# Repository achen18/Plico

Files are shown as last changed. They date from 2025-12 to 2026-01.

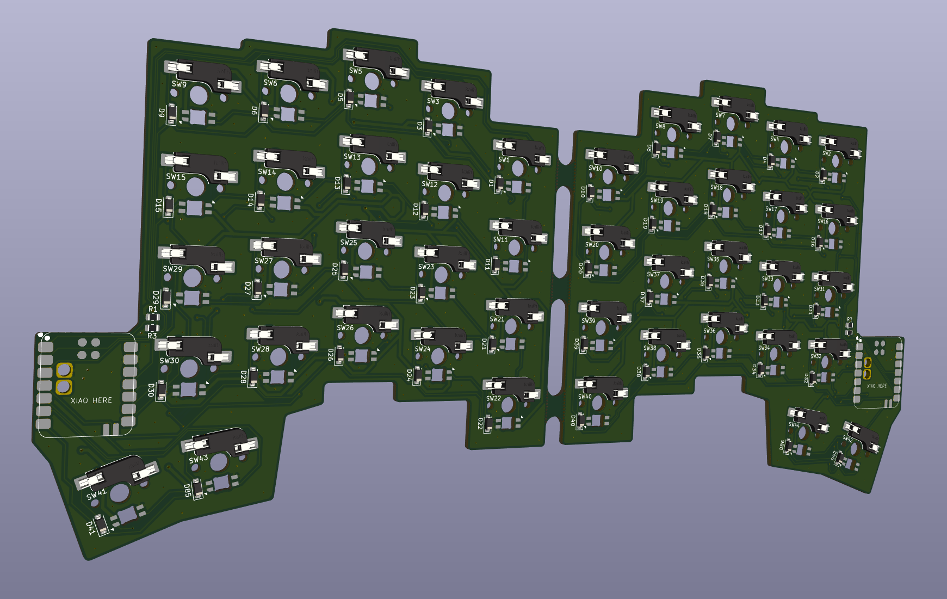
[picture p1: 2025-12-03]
pictures/pcb3DView.png

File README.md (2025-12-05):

# Plico
Fully custom split mechanical keyboard. Runs on ZMK software, controlling key functions and responsive lighting. Future iterations intend to use ultra low-profile switches and a case redesign to allow the two sides to fold together for portability. Firmware updates plan to incorporate layers and macros once the author thinks of what to use so many keys for. 



## PCB
Designed in Kicad

Schematic
schematic

PCB
pcbTraces
pcb3DView

## Case  
3d printed case desinged using Fusion 360. Multiple parts designed for printing with minimal supports. Designed such that no mounting holes needed in pcb. 



## Firmware  
Macropad runs on ZMK software.  
- Split keyboard Bluetooth connection
- 44 keys, full keyboard functionality
- Reactive key leds with fade out effects

To-Do
- Multiple layers for different day-to-day needs. Custom key to easily cycle between layers. Indicate current layer with rgb change. 

## Bill of Materials  
- 2 x XIAO-nRF52840-SMD
- 44 x 1N5819 SMD Diodes
- 44 x MX-Style switches
- 44 x Blank DSA keycaps
- 44 x SK6812-E Reverse Mount LEDs
- 2 x Resistors (1 806k, 1 2M)
- 10 x M3x10 Screws
- 10 x M3x5mx4mm heatset inserts
- 1 x Case (6 3D printed parts - 3 left/right)

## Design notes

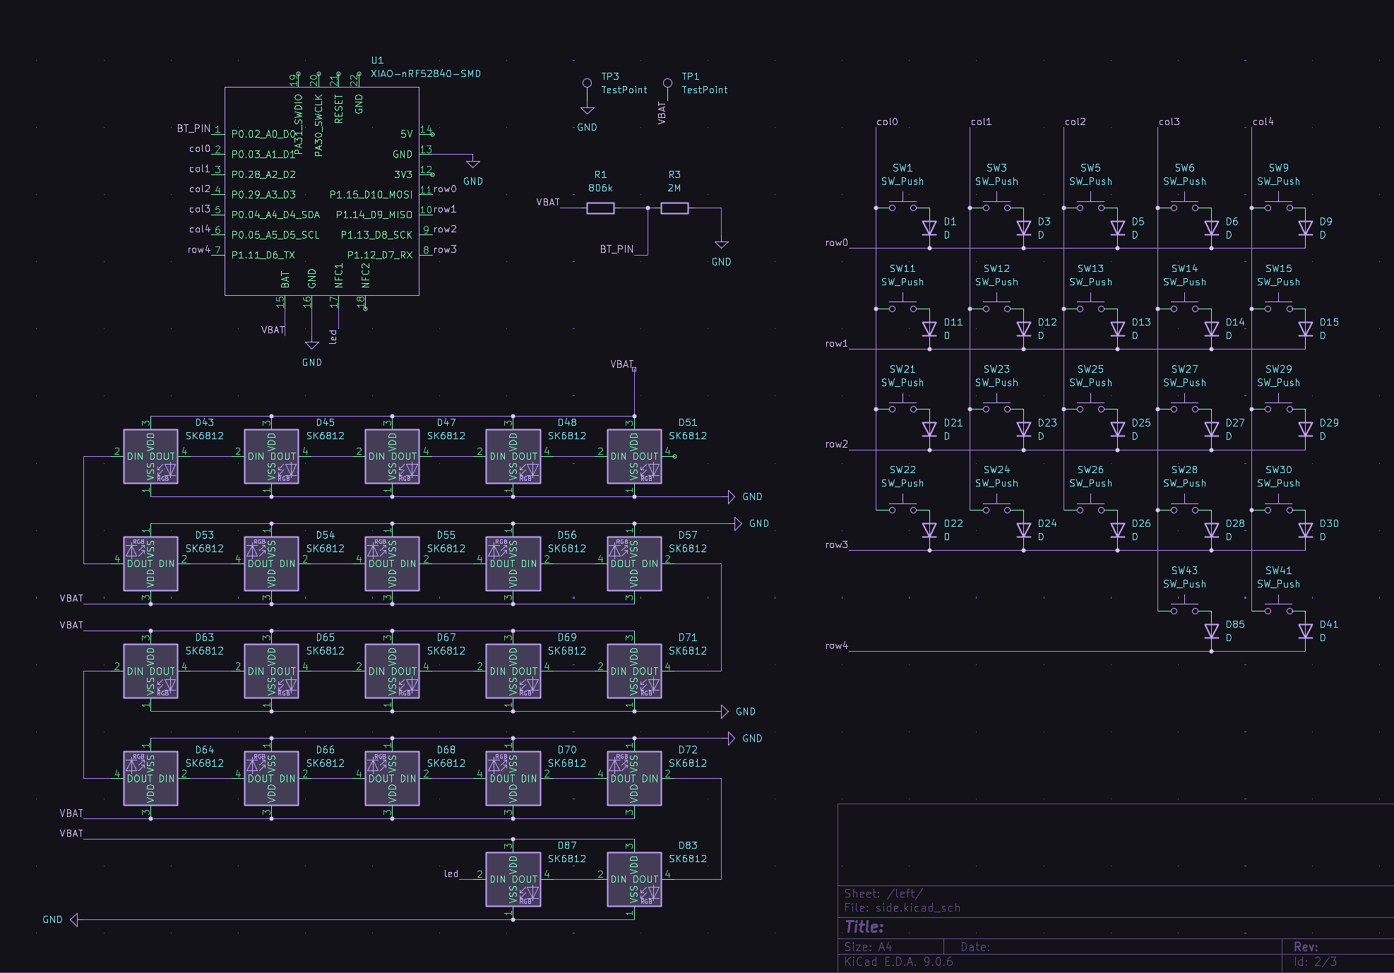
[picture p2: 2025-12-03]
pictures/schematic.png

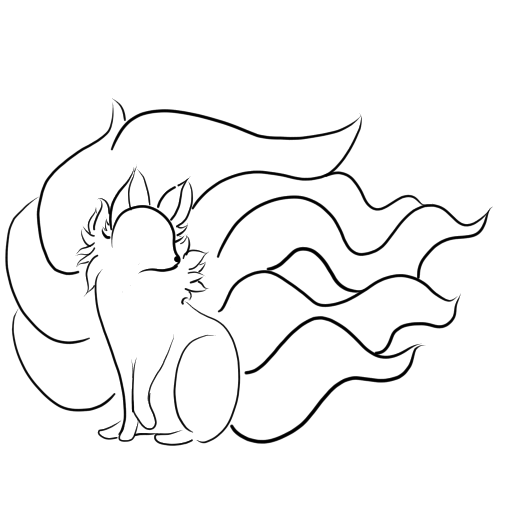
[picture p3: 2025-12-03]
pcb/assets/FoxProfilePurple.kra~.png

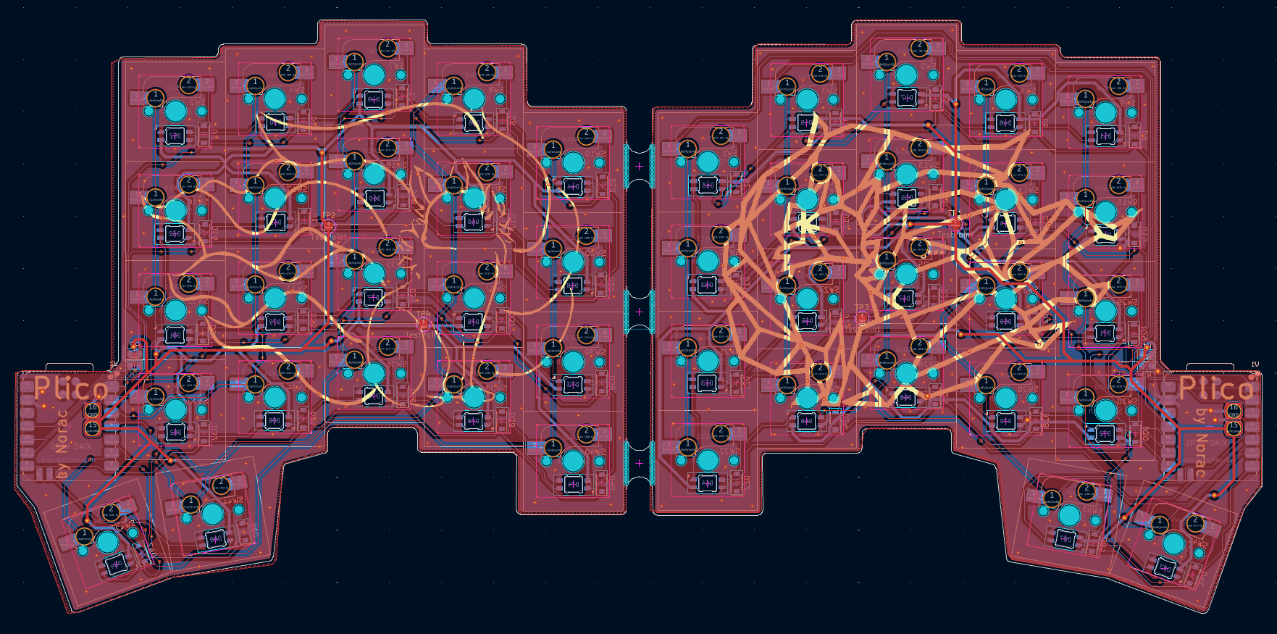
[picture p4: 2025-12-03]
pictures/pcbTraces.png

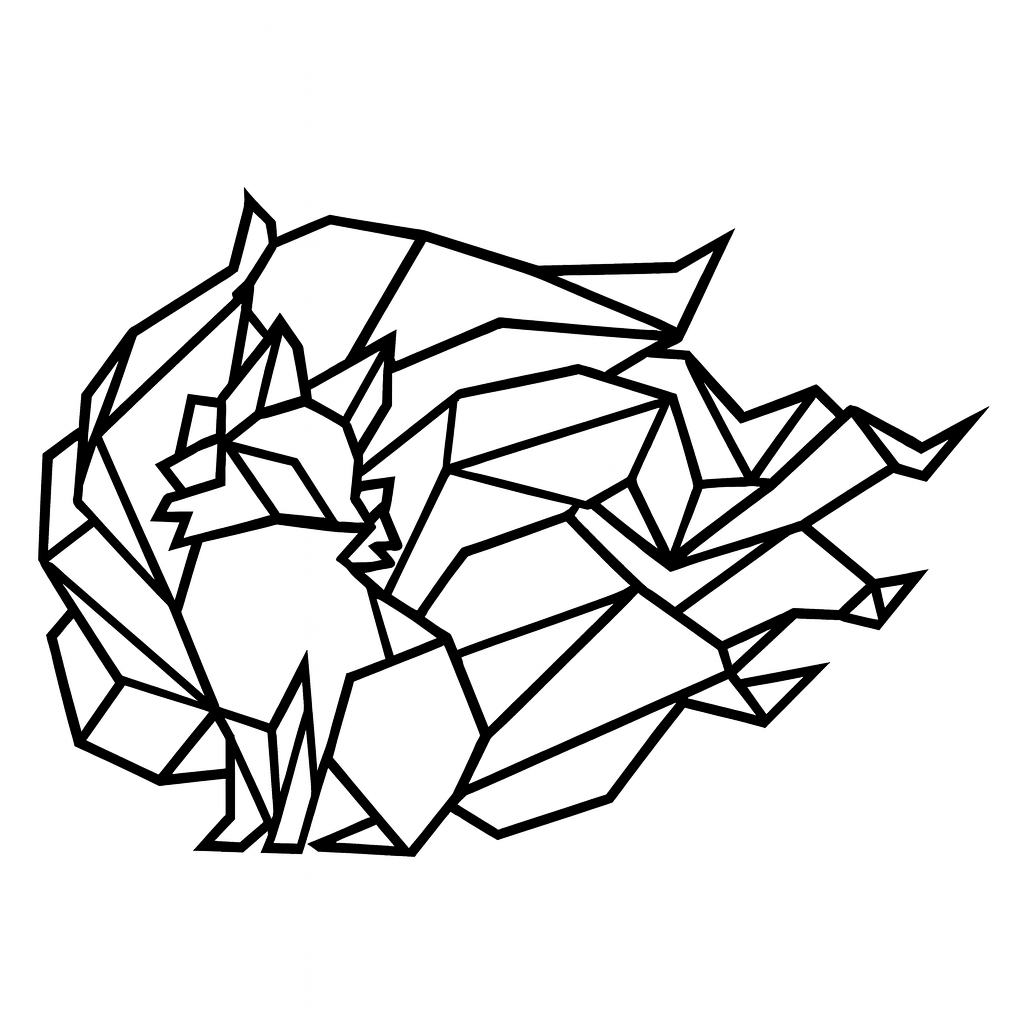
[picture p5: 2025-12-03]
pcb/assets/FoxProfileGeometric.png

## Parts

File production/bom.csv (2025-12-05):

Designator | Footprint | Quantity | Value | LCSC Part #
D1, D10, D11, D12, D13, D14, D15, D16, D17, D18, D19, D2, D20, D21, D22, D23, D24, D25, D26, D27, D28, D29, D3, D30, D31, D32, D33, D34, D35, D36, D37, D38, D39, D4, D40, D41, D42, D5, D6, D7, D8, D85, D86, D9 | D_SOD-123 | 44 | D
D43, D44, D45, D46, D47, D48, D49, D50, D51, D52, D53, D54, D55, D56, D57, D58, D59, D60, D61, D62, D63, D64, D65, D66, D67, D68, D69, D70, D71, D72, D73, D74, D75, D76, D77, D78, D79, D80, D81, D82, D83, D84, D87, D88 | Untitled | 44 | SK6812
R1, R2 | 0805 | 2 | 806k
R3, R4 | 0805 | 2 | 2M
SW1, SW10, SW11, SW12, SW13, SW14, SW15, SW16, SW17, SW18, SW19, SW2, SW20, SW21, SW22, SW23, SW24, SW25, SW26, SW27, SW28, SW29, SW3, SW30, SW31, SW32, SW33, SW34, SW35, SW36, SW37, SW38, SW39, SW4, SW40, SW41, SW42, SW43, SW44, SW5, SW6, SW7, SW8, SW9 | SW_MX_HS_CPG151101S11_1u | 44 | SW_Push
TP1, TP2, TP3, TP4 | TestPoint_Pad_D2.0mm | 4 | TestPoint
U1, U2 | modified-XIAO-nRF52840-SMD | 2 | XIAO-nRF52840-SMD

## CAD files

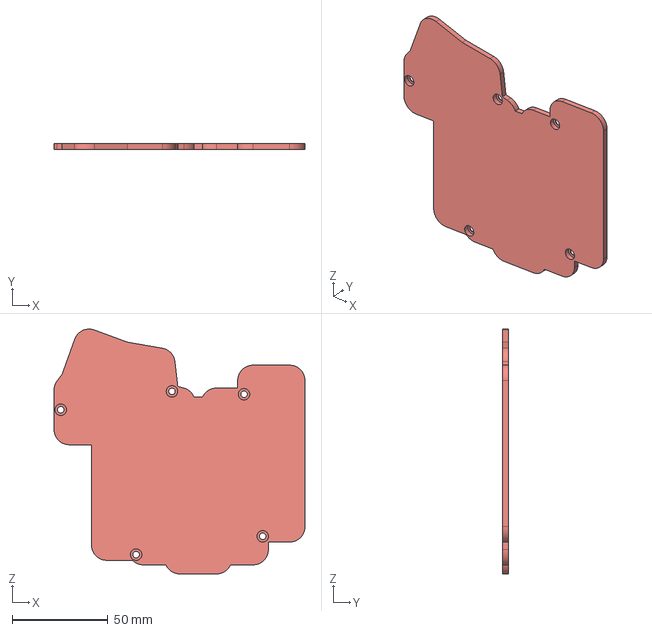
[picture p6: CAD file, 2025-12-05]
cad/bottomRight.step
130.8 x 3.00 x 127.6 mm

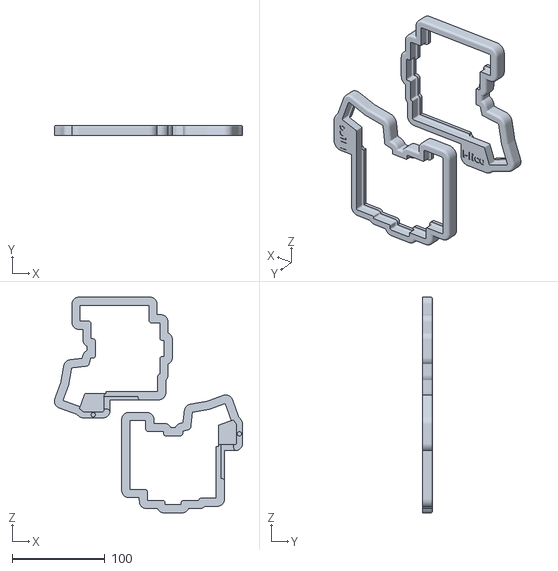
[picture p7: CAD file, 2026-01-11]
production/cad/tops.stl
203.4 x 11.0 x 233.5

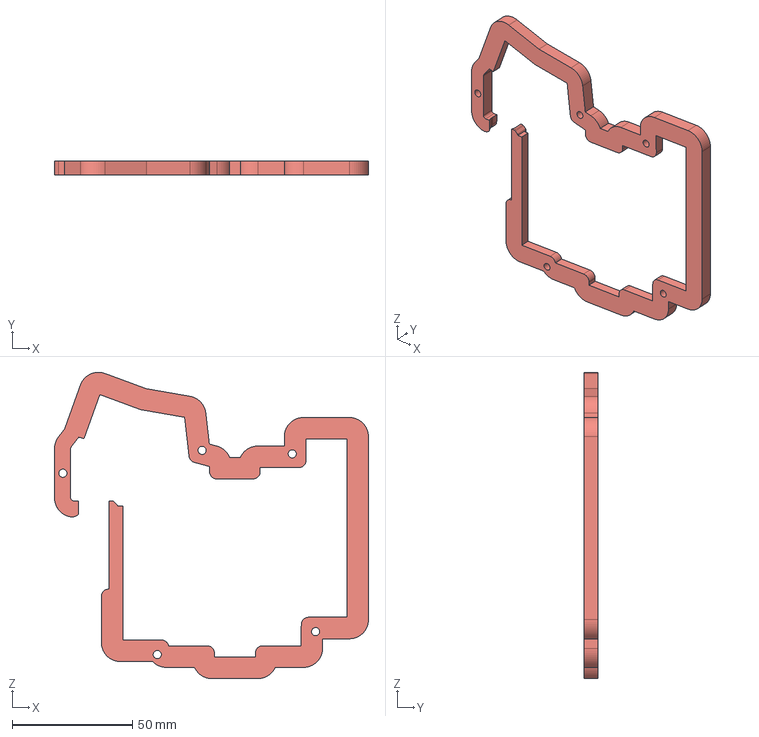
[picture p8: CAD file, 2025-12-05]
cad/middleRight.step
130.8 x 6.01 x 127.6 mm

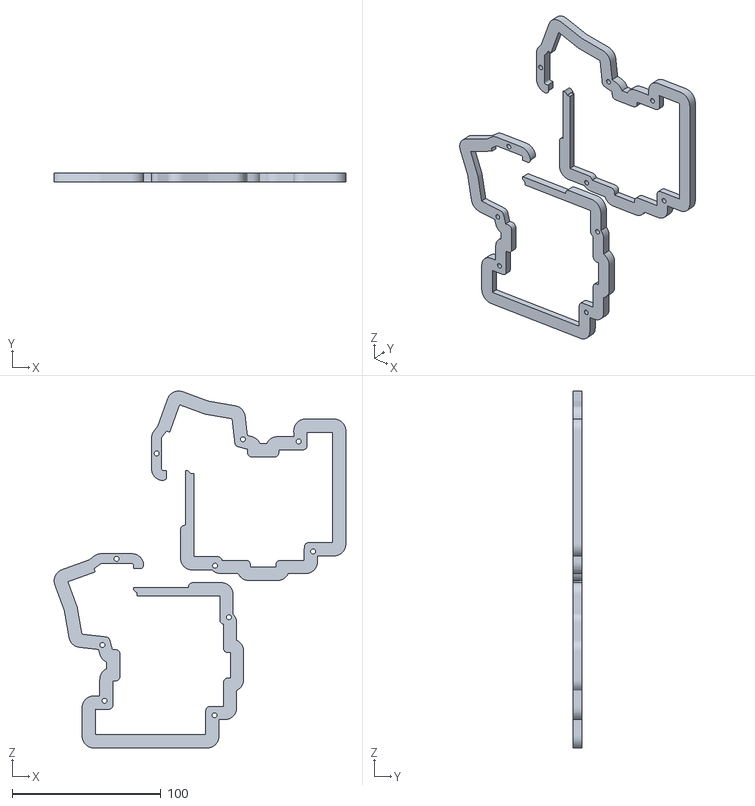
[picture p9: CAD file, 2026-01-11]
production/cad/middles.stl
196.4 x 6.01 x 240.3

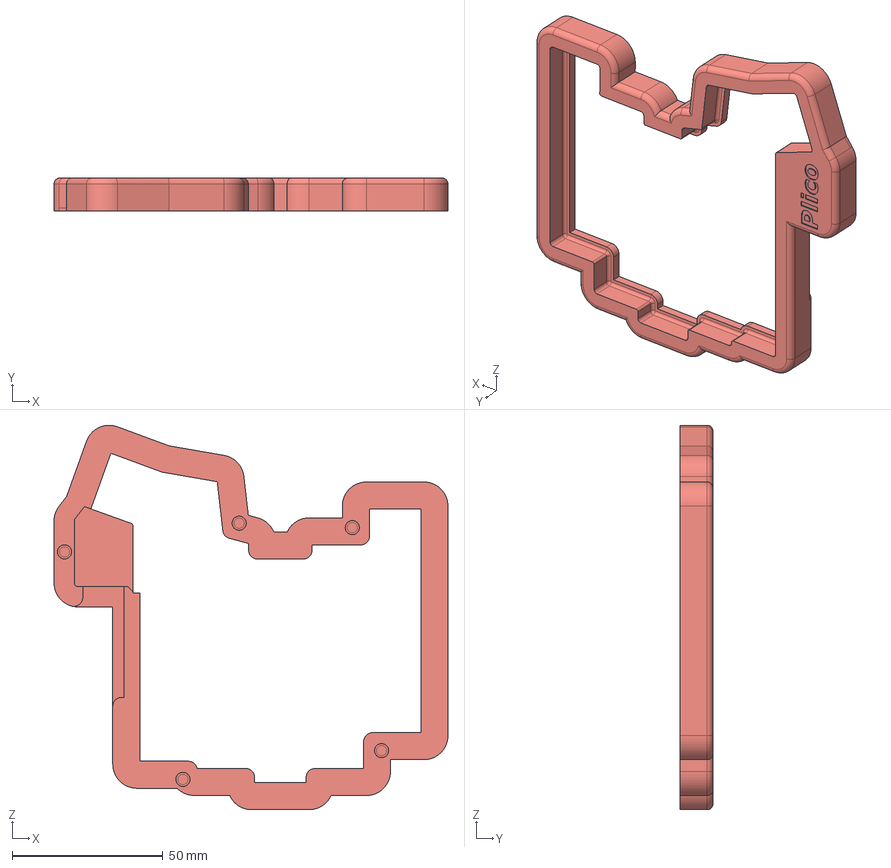
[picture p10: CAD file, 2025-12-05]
cad/topRight.step
130.8 x 11.0 x 127.6 mm

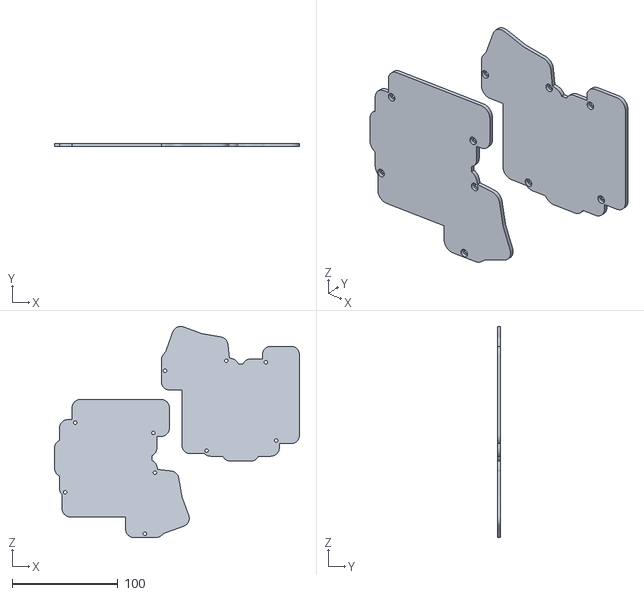
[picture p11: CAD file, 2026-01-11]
production/cad/bottoms.stl
231.9 x 3.00 x 199.9

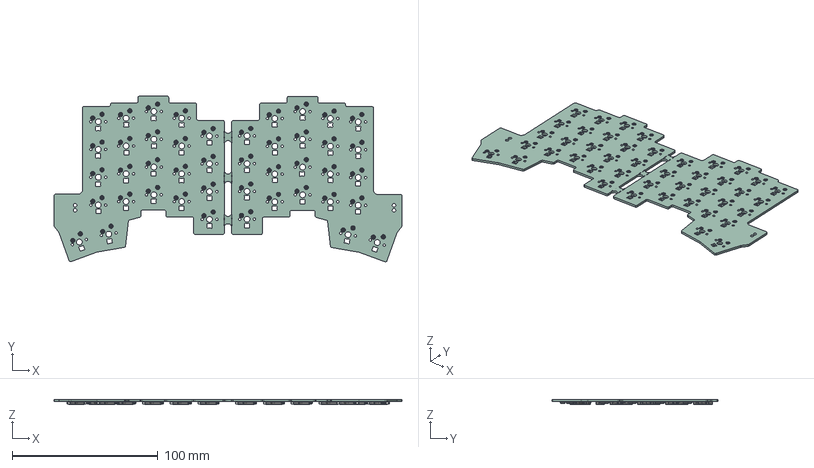
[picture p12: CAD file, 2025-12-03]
cad/Plico.step
238.6 x 113.7 x 3.42 mm
D_SOD-123 x 44
Contact x 88
R_0805_2012Metric x 4
Plico_PCB

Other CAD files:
cad/bottomLeft.step
production/cad/middleLeft.step
cad/topLeft.step
production/cad/bottomLeft.step
cad/middleLeft.step
production/cad/topLeft.step
production/cad/bottomLeft.stl
production/cad/bottomRight.stl
production/cad/middleLeft.stl
production/cad/middleRight.stl
production/cad/topLeft.stl
production/cad/topRight.stl

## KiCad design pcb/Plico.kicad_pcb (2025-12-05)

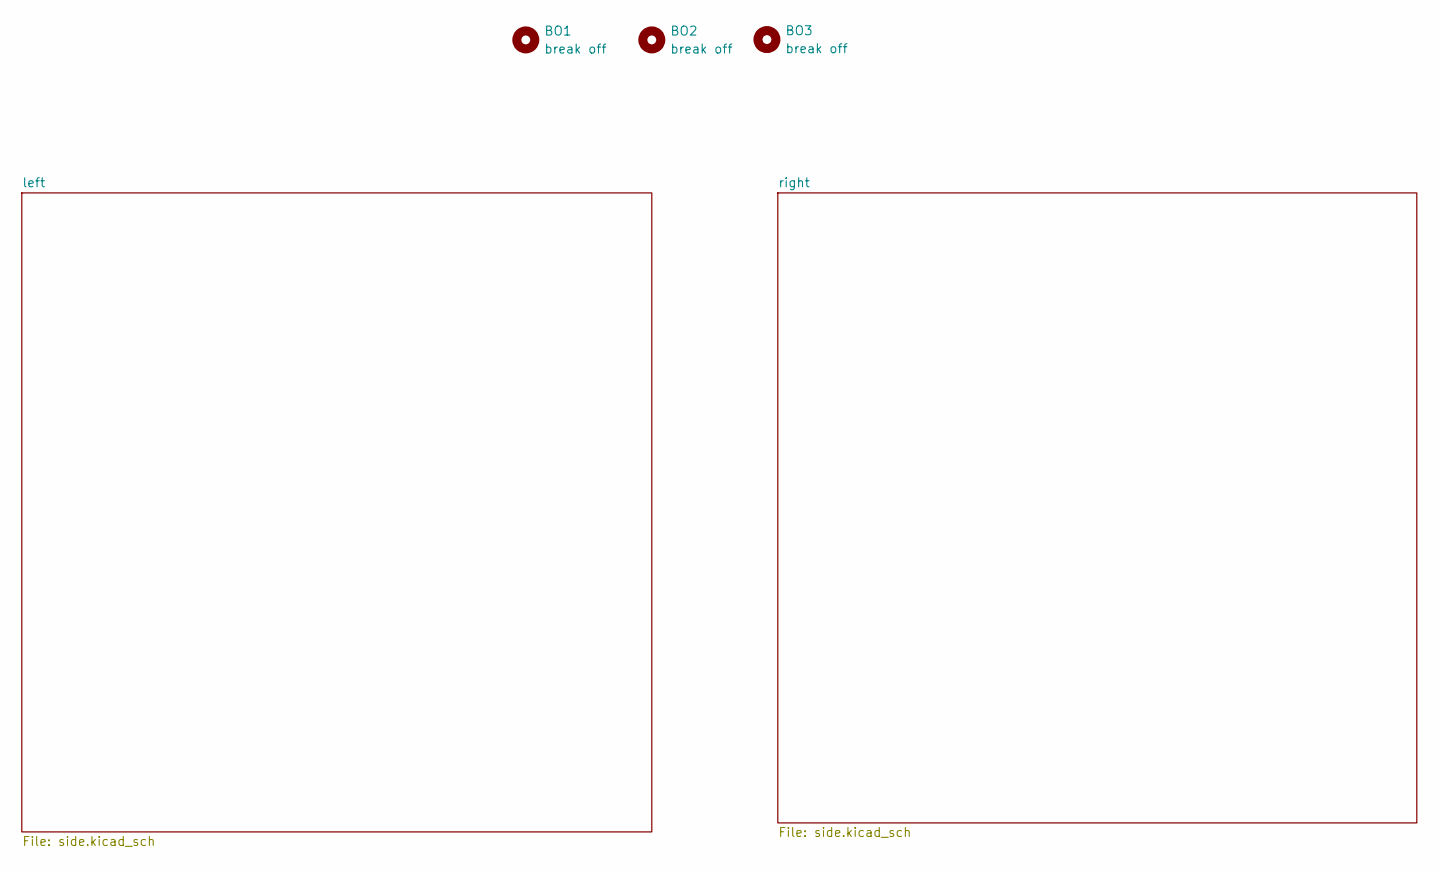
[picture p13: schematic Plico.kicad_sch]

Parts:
BO1, BO2, BO3: break off; mouse-bite-5mm-slot-edgeCuts

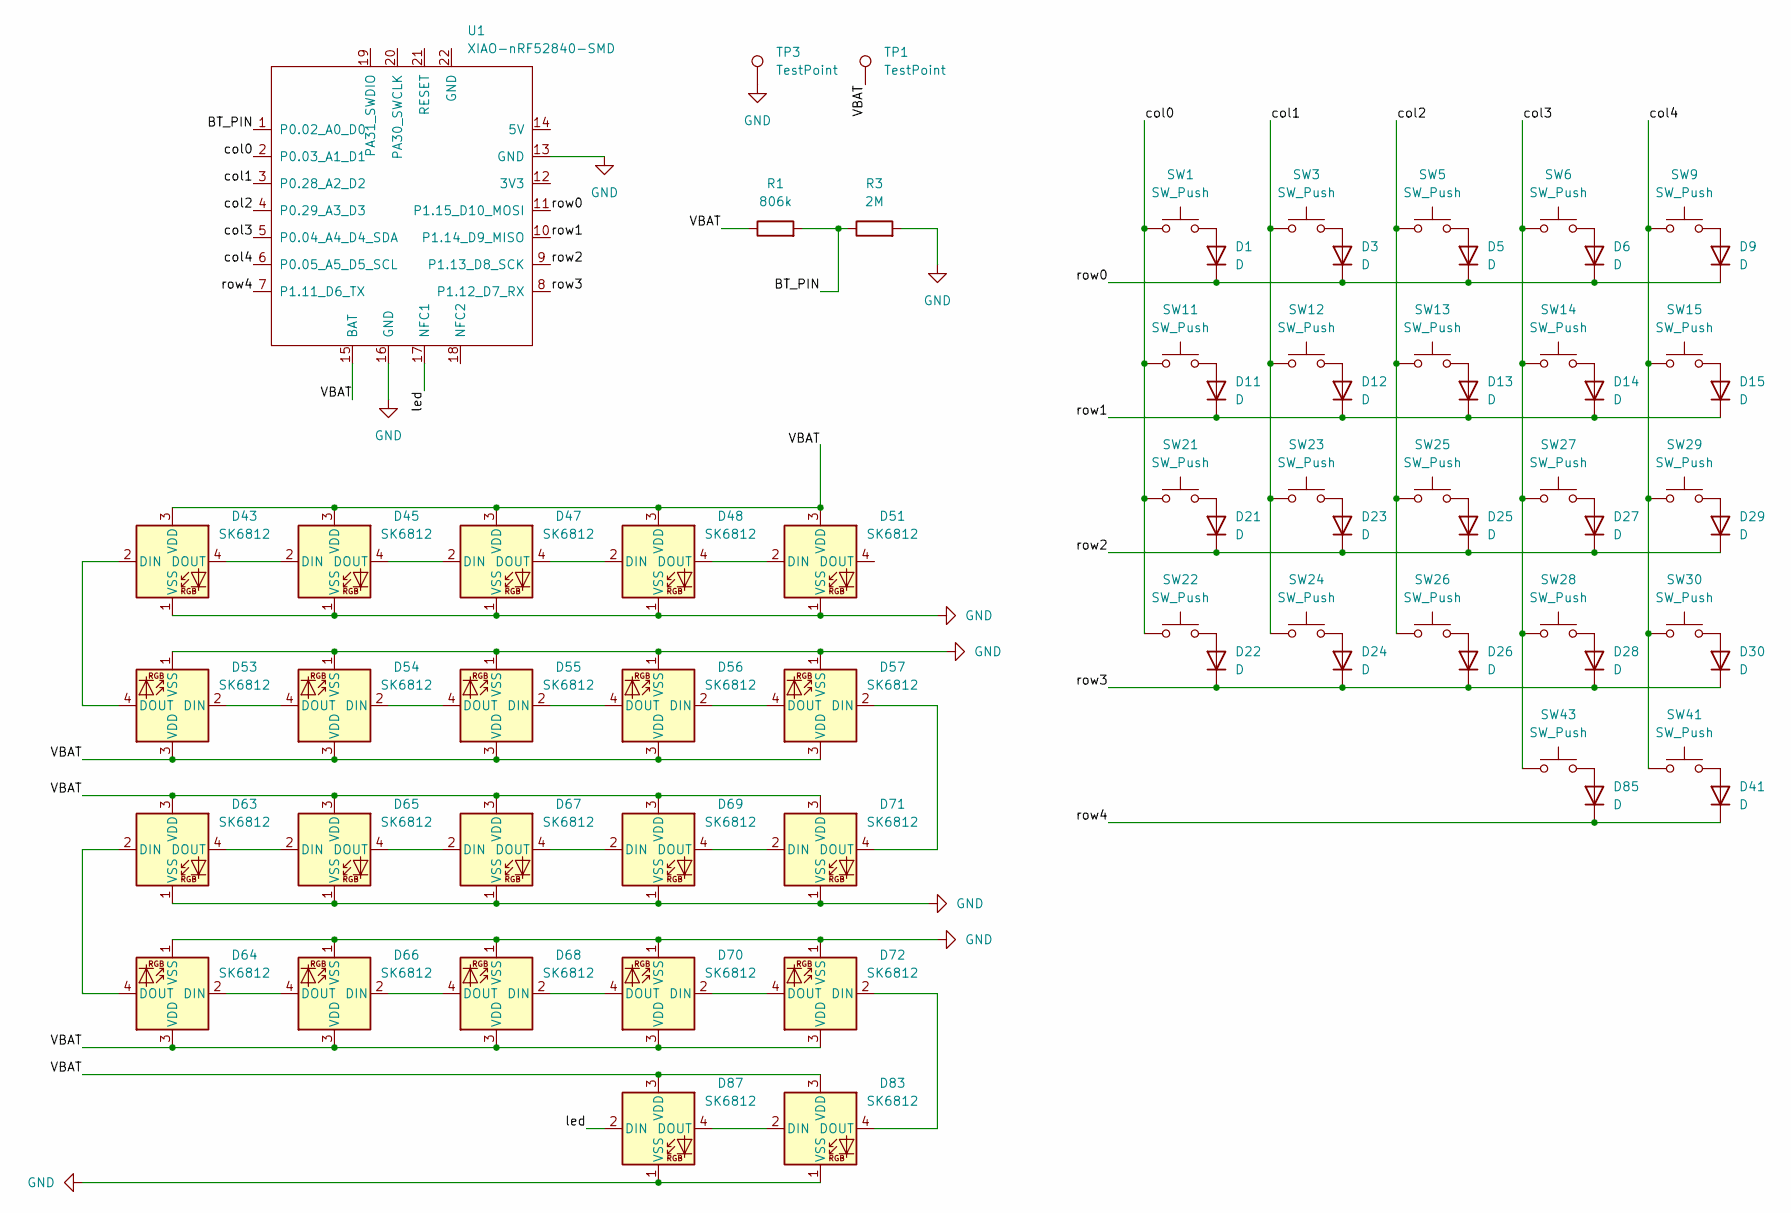
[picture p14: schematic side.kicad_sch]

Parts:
D1, D3, D5, D6, D9, D11, D12, D13, D14, D15, D21, D22, D23, D24, D25, D26, D27, D28, D29, D30, D41, D85: D; D_SOD-123
D43, D45, D47, D48, D51, D53, D54, D55, D56, D57, D63, D64, D65, D66, D67, D68, D69, D70, D71, D72, D83, D87: SK6812; Untitled
R1: 806k; R_0805_2012Metric
R3: 2M; R_0805_2012Metric
SW1, SW3, SW5, SW6, SW9, SW11, SW12, SW13, SW14, SW15, SW21, SW22, SW23, SW24, SW25, SW26, SW27, SW28, SW29, SW30, SW41, SW43: SW_Push; SW_MX_HS_CPG151101S11_1u
TP1, TP3: TestPoint; TestPoint_Pad_D2.0mm
U1: XIAO-nRF52840-SMD; modified-XIAO-nRF52840-SMD

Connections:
/left/BT_PIN: R1.2, R3.1, U1.1 (P0.02_A0_D0)
/left/VBAT: D43.3 (VDD), D45.3 (VDD), D47.3 (VDD), D48.3 (VDD), D51.3 (VDD), D53.3 (VDD), D54.3 (VDD), D55.3 (VDD), D56.3 (VDD), D57.3 (VDD), D63.3 (VDD), D64.3 (VDD), D65.3 (VDD), D66.3 (VDD), D67.3 (VDD), D68.3 (VDD), D69.3 (VDD), D70.3 (VDD), D71.3 (VDD), D72.3 (VDD), D83.3 (VDD), D87.3 (VDD), R1.1, TP1.1, U1.15 (BAT)
/left/col0: SW1.1, SW11.1, SW21.1, SW22.1, U1.2 (P0.03_A1_D1)
/left/col1: SW3.1, SW12.1, SW23.1, SW24.1, U1.3 (P0.28_A2_D2)
/left/col2: SW5.1, SW13.1, SW25.1, SW26.1, U1.4 (P0.29_A3_D3)
/left/col3: SW6.1, SW14.1, SW27.1, SW28.1, SW43.1, U1.5 (P0.04_A4_D4_SDA)
/left/col4: SW9.1, SW15.1, SW29.1, SW30.1, SW41.1, U1.6 (P0.05_A5_D5_SCL)
/left/led: D87.2 (DIN), U1.17 (NFC1)
/left/row0: D1.1 (K), D3.1 (K), D5.1 (K), D6.1 (K), D9.1 (K), U1.11 (P1.15_D10_MOSI)
/left/row1: D11.1 (K), D12.1 (K), D13.1 (K), D14.1 (K), D15.1 (K), U1.10 (P1.14_D9_MISO)
/left/row2: D21.1 (K), D23.1 (K), D25.1 (K), D27.1 (K), D29.1 (K), U1.9 (P1.13_D8_SCK)
/left/row3: D22.1 (K), D24.1 (K), D26.1 (K), D28.1 (K), D30.1 (K), U1.8 (P1.12_D7_RX)
/left/row4: D41.1 (K), D85.1 (K), U1.7 (P1.11_D6_TX)
GND: D43.1 (VSS), D45.1 (VSS), D47.1 (VSS), D48.1 (VSS), D51.1 (VSS), D53.1 (VSS), D54.1 (VSS), D55.1 (VSS), D56.1 (VSS), D57.1 (VSS), D63.1 (VSS), D64.1 (VSS), D65.1 (VSS), D66.1 (VSS), D67.1 (VSS), D68.1 (VSS), D69.1 (VSS), D70.1 (VSS), D71.1 (VSS), D72.1 (VSS), D83.1 (VSS), D87.1 (VSS), R3.2, TP3.1, U1.13 (GND), U1.16 (GND); also elsewhere on the board
unnamed: D1.2 (A), SW1.2
unnamed: D3.2 (A), SW3.2
unnamed: D5.2 (A), SW5.2
unnamed: D6.2 (A), SW6.2
unnamed: D9.2 (A), SW9.2
unnamed: D11.2 (A), SW11.2
unnamed: D12.2 (A), SW12.2
unnamed: D13.2 (A), SW13.2
unnamed: D14.2 (A), SW14.2
unnamed: D15.2 (A), SW15.2
unnamed: D21.2 (A), SW21.2
unnamed: D22.2 (A), SW22.2
unnamed: D23.2 (A), SW23.2
unnamed: D24.2 (A), SW24.2
unnamed: D25.2 (A), SW25.2
unnamed: D26.2 (A), SW26.2
unnamed: D27.2 (A), SW27.2
unnamed: D28.2 (A), SW28.2
unnamed: D29.2 (A), SW29.2
unnamed: D30.2 (A), SW30.2
unnamed: D41.2 (A), SW41.2
unnamed: D43.2 (DIN), D53.4 (DOUT)
unnamed: D43.4 (DOUT), D45.2 (DIN)
unnamed: D45.4 (DOUT), D47.2 (DIN)
unnamed: D47.4 (DOUT), D48.2 (DIN)
unnamed: D48.4 (DOUT), D51.2 (DIN)
unnamed: D53.2 (DIN), D54.4 (DOUT)
unnamed: D54.2 (DIN), D55.4 (DOUT)
unnamed: D55.2 (DIN), D56.4 (DOUT)
unnamed: D56.2 (DIN), D57.4 (DOUT)
unnamed: D57.2 (DIN), D71.4 (DOUT)
unnamed: D63.2 (DIN), D64.4 (DOUT)
unnamed: D63.4 (DOUT), D65.2 (DIN)
unnamed: D64.2 (DIN), D66.4 (DOUT)
unnamed: D65.4 (DOUT), D67.2 (DIN)
unnamed: D66.2 (DIN), D68.4 (DOUT)
unnamed: D67.4 (DOUT), D69.2 (DIN)
unnamed: D68.2 (DIN), D70.4 (DOUT)
unnamed: D69.4 (DOUT), D71.2 (DIN)
unnamed: D70.2 (DIN), D72.4 (DOUT)
unnamed: D72.2 (DIN), D83.4 (DOUT)
unnamed: D83.2 (DIN), D87.4 (DOUT)
unnamed: D85.2 (A), SW43.2

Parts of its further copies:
D2, D4, D7, D8, D10, D16, D17, D18, D19, D20, D31, D32, D33, D34, D35, D36, D37, D38, D39, D40, D42, D86: D; D_SOD-123
D44, D46, D49, D50, D52, D58, D59, D60, D61, D62, D73, D74, D75, D76, D77, D78, D79, D80, D81, D82, D84, D88: SK6812; Untitled
R2: 806k; R_0805_2012Metric
R4: 2M; R_0805_2012Metric
SW2, SW4, SW7, SW8, SW10, SW16, SW17, SW18, SW19, SW20, SW31, SW32, SW33, SW34, SW35, SW36, SW37, SW38, SW39, SW40, SW42, SW44: SW_Push; SW_MX_HS_CPG151101S11_1u
TP2, TP4: TestPoint; TestPoint_Pad_D2.0mm
U2: XIAO-nRF52840-SMD; modified-XIAO-nRF52840-SMD

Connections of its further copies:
/right/BT_PIN: R2.2, R4.1, U2.1 (P0.02_A0_D0)
/right/VBAT: D44.3 (VDD), D46.3 (VDD), D49.3 (VDD), D50.3 (VDD), D52.3 (VDD), D58.3 (VDD), D59.3 (VDD), D60.3 (VDD), D61.3 (VDD), D62.3 (VDD), D73.3 (VDD), D74.3 (VDD), D75.3 (VDD), D76.3 (VDD), D77.3 (VDD), D78.3 (VDD), D79.3 (VDD), D80.3 (VDD), D81.3 (VDD), D82.3 (VDD), D84.3 (VDD), D88.3 (VDD), R2.1, TP2.1, U2.15 (BAT)
/right/col0: SW2.1, SW16.1, SW31.1, SW32.1, U2.2 (P0.03_A1_D1)
/right/col1: SW4.1, SW17.1, SW33.1, SW34.1, U2.3 (P0.28_A2_D2)
/right/col2: SW7.1, SW18.1, SW35.1, SW36.1, U2.4 (P0.29_A3_D3)
/right/col3: SW8.1, SW19.1, SW37.1, SW38.1, SW44.1, U2.5 (P0.04_A4_D4_SDA)
/right/col4: SW10.1, SW20.1, SW39.1, SW40.1, SW42.1, U2.6 (P0.05_A5_D5_SCL)
/right/led: D88.2 (DIN), U2.17 (NFC1)
/right/row0: D2.1 (K), D4.1 (K), D7.1 (K), D8.1 (K), D10.1 (K), U2.11 (P1.15_D10_MOSI)
/right/row1: D16.1 (K), D17.1 (K), D18.1 (K), D19.1 (K), D20.1 (K), U2.10 (P1.14_D9_MISO)
/right/row2: D31.1 (K), D33.1 (K), D35.1 (K), D37.1 (K), D39.1 (K), U2.9 (P1.13_D8_SCK)
/right/row3: D32.1 (K), D34.1 (K), D36.1 (K), D38.1 (K), D40.1 (K), U2.8 (P1.12_D7_RX)
/right/row4: D42.1 (K), D86.1 (K), U2.7 (P1.11_D6_TX)
GND: D44.1 (VSS), D46.1 (VSS), D49.1 (VSS), D50.1 (VSS), D52.1 (VSS), D58.1 (VSS), D59.1 (VSS), D60.1 (VSS), D61.1 (VSS), D62.1 (VSS), D73.1 (VSS), D74.1 (VSS), D75.1 (VSS), D76.1 (VSS), D77.1 (VSS), D78.1 (VSS), D79.1 (VSS), D80.1 (VSS), D81.1 (VSS), D82.1 (VSS), D84.1 (VSS), D88.1 (VSS), R4.2, TP4.1, U2.13 (GND), U2.16 (GND); also elsewhere on the board
unnamed: D2.2 (A), SW2.2
unnamed: D4.2 (A), SW4.2
unnamed: D7.2 (A), SW7.2
unnamed: D8.2 (A), SW8.2
unnamed: D10.2 (A), SW10.2
unnamed: D16.2 (A), SW16.2
unnamed: D17.2 (A), SW17.2
unnamed: D18.2 (A), SW18.2
unnamed: D19.2 (A), SW19.2
unnamed: D20.2 (A), SW20.2
unnamed: D31.2 (A), SW31.2
unnamed: D32.2 (A), SW32.2
unnamed: D33.2 (A), SW33.2
unnamed: D34.2 (A), SW34.2
unnamed: D35.2 (A), SW35.2
unnamed: D36.2 (A), SW36.2
unnamed: D37.2 (A), SW37.2
unnamed: D38.2 (A), SW38.2
unnamed: D39.2 (A), SW39.2
unnamed: D40.2 (A), SW40.2
unnamed: D42.2 (A), SW42.2
unnamed: D44.2 (DIN), D58.4 (DOUT)
unnamed: D44.4 (DOUT), D46.2 (DIN)
unnamed: D46.4 (DOUT), D49.2 (DIN)
unnamed: D49.4 (DOUT), D50.2 (DIN)
unnamed: D50.4 (DOUT), D52.2 (DIN)
unnamed: D58.2 (DIN), D59.4 (DOUT)
unnamed: D59.2 (DIN), D60.4 (DOUT)
unnamed: D60.2 (DIN), D61.4 (DOUT)
unnamed: D61.2 (DIN), D62.4 (DOUT)
unnamed: D62.2 (DIN), D81.4 (DOUT)
unnamed: D73.2 (DIN), D74.4 (DOUT)
unnamed: D73.4 (DOUT), D75.2 (DIN)
unnamed: D74.2 (DIN), D76.4 (DOUT)
unnamed: D75.4 (DOUT), D77.2 (DIN)
unnamed: D76.2 (DIN), D78.4 (DOUT)
unnamed: D77.4 (DOUT), D79.2 (DIN)
unnamed: D78.2 (DIN), D80.4 (DOUT)
unnamed: D79.4 (DOUT), D81.2 (DIN)
unnamed: D80.2 (DIN), D82.4 (DOUT)
unnamed: D82.2 (DIN), D84.4 (DOUT)
unnamed: D84.2 (DIN), D88.4 (DOUT)
unnamed: D86.2 (A), SW44.2

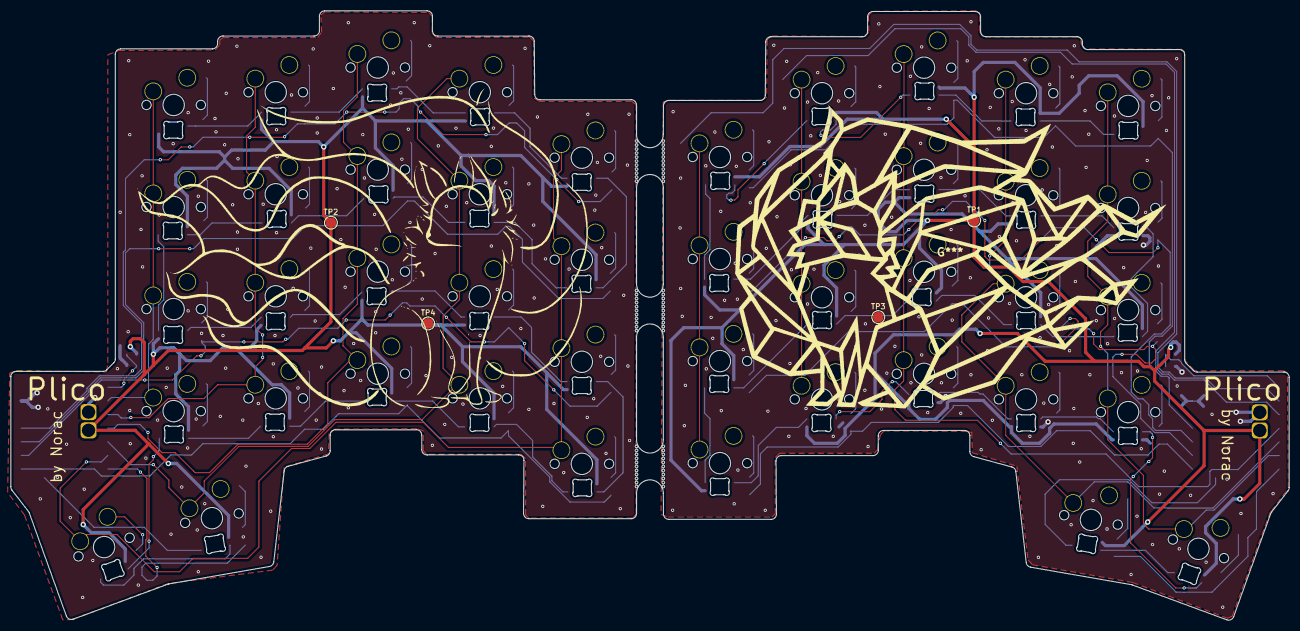
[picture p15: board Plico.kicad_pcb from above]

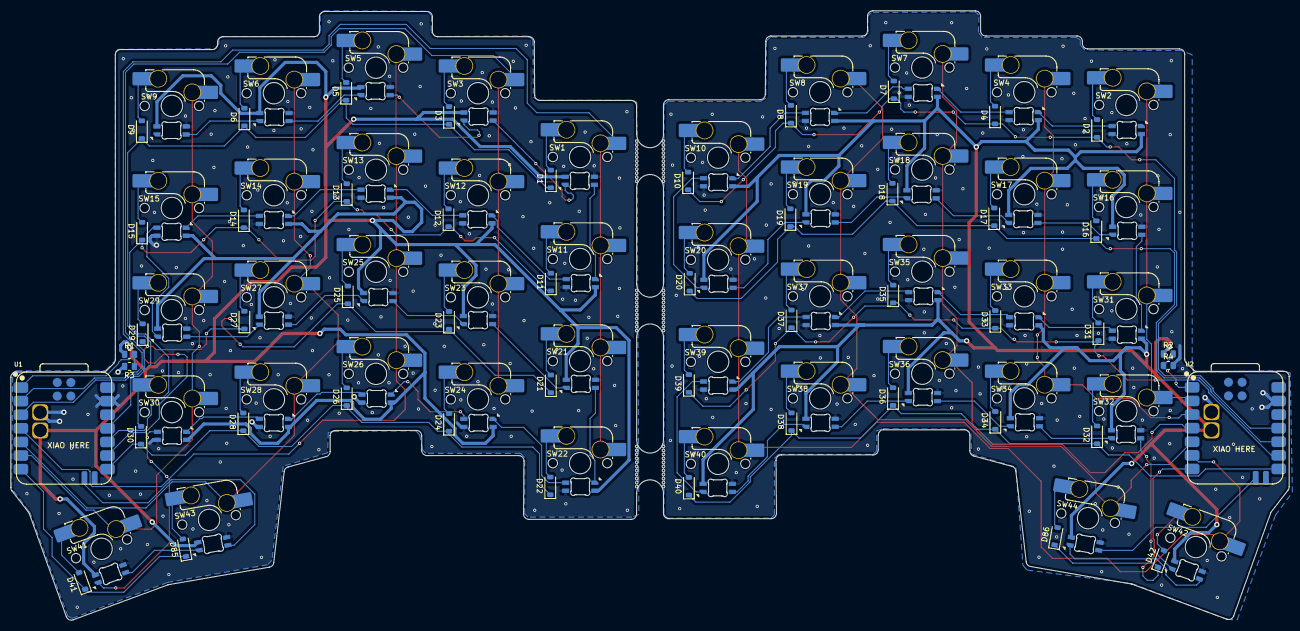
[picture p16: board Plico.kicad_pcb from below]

Board: 2 copper layers, 238.6 x 113.7 mm, 145 parts (138 on the bottom side), 113 nets.

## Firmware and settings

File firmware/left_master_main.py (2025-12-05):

import board
import time

from kmk.kmk_keyboard import KMKKeyboard
from kmk.scanners import DiodeOrientation
from kmk.keys import KC, Key
from kmk.modules.split import Split, SplitType, SplitSide
from kmk.extensions.RGB import RGB

class LedKey(Key):
    def __init__(self, key, led_index, hue=280, sat=255, val=255, fade_steps=5):
        self.key = key
        self.led_index = led_index
        self.hue = hue
        self.sat = sat
        self.val = val
        self.fade_steps = fade_steps

    def on_press(self, keyboard, coord_int=None):
        keyboard.add_key(self.key)
        keyboard.rgb.set_hsv(self.hue, self.sat, self.val, self.led_index)
        keyboard.rgb.show()

    def on_release(self, keyboard, coord_int=None):
        keyboard.remove_key(self.key)
        # Fade LED gradually
        for i in range(self.fade_steps, 0, -1):
            keyboard.rgb.set_hsv(self.hue, self.sat, int(self.val * i / self.fade_steps), self.led_index)
            keyboard.rgb.show()
            time.sleep(0.02)  # optional; may need adjustment for BLE

keyboard = KMKKeyboard()

# Matrix pins
keyboard.col_pins = (
    board.D1,    # col 0
    board.D2,    # col 1
    board.D3,    # col 2
    board.D4,    # col 3
    board.D5,    # col 4
)

keyboard.row_pins = (
    board.D10,   # row 0
    board.D9,    # row 1
    board.D8,    # row 2
    board.D7,    # row 3
    board.D6,    # row 4
)

# Diode direction: Column to Row
keyboard.diode_orientation = DiodeOrientation.COL2ROW

# Keymap
keyboard.keymap = [
    [LedKey(KC.N1,0), LedKey(KC.N2,1), LedKey(KC.N3,2), LedKey(KC.N4,3), LedKey(KC.N5,4)],
    [LedKey(KC.Q,5), LedKey(KC.W,6), LedKey(KC.E,7), LedKey(KC.R,8), LedKey(KC.T,9)],
    [LedKey(KC.A,10), LedKey(KC.S,11), LedKey(KC.D,12), LedKey(KC.F,13), LedKey(KC.G,14)],
    [LedKey(KC.Z,15), LedKey(KC.X,16), LedKey(KC.C,17), LedKey(KC.V,18), LedKey(KC.B,19)],
    [KC.NO, KC.NO, KC.NO, LedKey(KC.LCTL,21), LedKey(KC.LSFT,20)]
]

split = Split(
    split_type=SplitType.BLE,
    split_side=SplitSide.LEFT
)
keyboard.modules.append(split)

rgb = RGB(
    pixel_pin=board.NFC1,
    num_pixels=22,
    rgb_order=(1, 0, 2),      # Standard R,G,B order; change if needed
    hue_default=0,             # Default hue at boot
    sat_default=255,           # Default saturation
    val_default=255,           # Default brightness (half brightness)
    val_limit=255              # Maximum brightness allowed
)
keyboard.extensions.append(rgb)


if __name__ == "__main__":
    keyboard.go()

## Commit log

2025-12-03 upload
    upload files, no screws in pcb, not started on firmware
    [Plico.kicad_pcb, Plico.kicad_sch, Plico.step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]
2025-12-05 final ?
    am done ?
    [Plico.kicad_pcb, bom.csv, bottomLeft.step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]
2026-01-11 Add case left stl's
    [bottomLeft.stl, middleLeft.stl, topLeft.stl]
2026-01-11 Add 3D-print optimized stl's
    [bottoms.stl, middles.stl, tops.stl]
